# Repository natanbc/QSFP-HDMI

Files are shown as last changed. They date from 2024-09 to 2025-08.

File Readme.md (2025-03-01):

# QSFP to HDMI Breakout Boards

This repository contains two KiCad subprojects for the QSFP to HDMI breakout boards. These subprojects are designed to facilitate the conversion of QSFP signals to HDMI.

The concept has been created to be used on the Microsoft Stratix V FPGA accelerator card "Storey Peak". Jan Marjanovic has created a series of posts about the analysis of the card:

- [Part 1](https://j-marjanovic.io/stratix-v-accelerator-card-from-ebay.html)
- [Part 2](https://j-marjanovic.io/stratix-v-accelerator-card-from-ebay-part-2.html)
- [Part 3](https://j-marjanovic.io/stratix-v-accelerator-card-from-ebay-part-3.html)
- [Part 4](https://j-marjanovic.io/stratix-v-accelerator-card-from-ebay-part-4.html)
- [Part 5](https://j-marjanovic.io/stratix-v-accelerator-card-from-ebay-part-5.html)
- [Part 6](https://j-marjanovic.io/stratix-v-accelerator-card-from-ebay-part-6.html)
- [Part 7](https://j-marjanovic.io/stratix-v-accelerator-card-from-ebay-part-7.html)
- [Part 8](https://j-marjanovic.io/stratix-v-accelerator-card-from-ebay-part-8.html)

## Subprojects

### 1. QSFP breakout board

The project is just a breakout board for the QSFP connector allowing connection to the QSFP on the FPGA board.

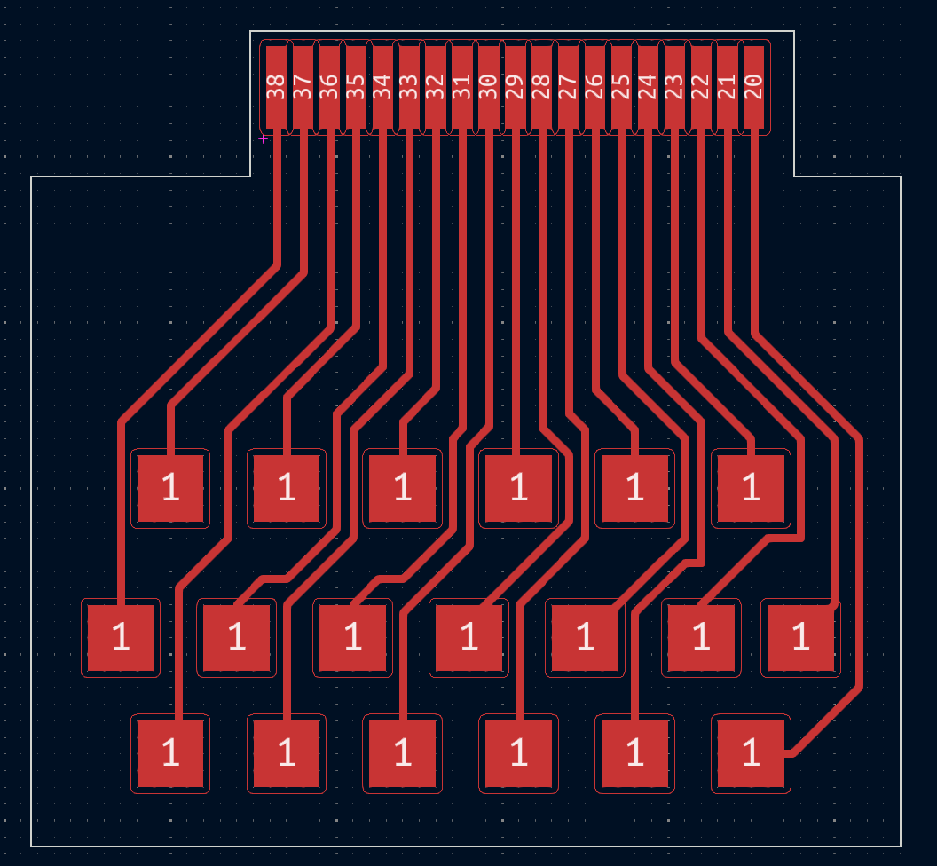
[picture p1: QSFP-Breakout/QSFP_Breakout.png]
PCB


### 2. QSFP to HDMI and UART Adapter

This subproject focuses on the design and implementation of an adapter that converts QSFP signals to HDMI. The key features include:

- QSFP connector for input signals
- HDMI connector for output signals
- USB-C connector for UART adapter

This board has been manufactured in JLCPCB, and has LCSC part numbers allowing assembly by them as well. Be sure to use 1mm PCBs to fit into the QSFP slot.

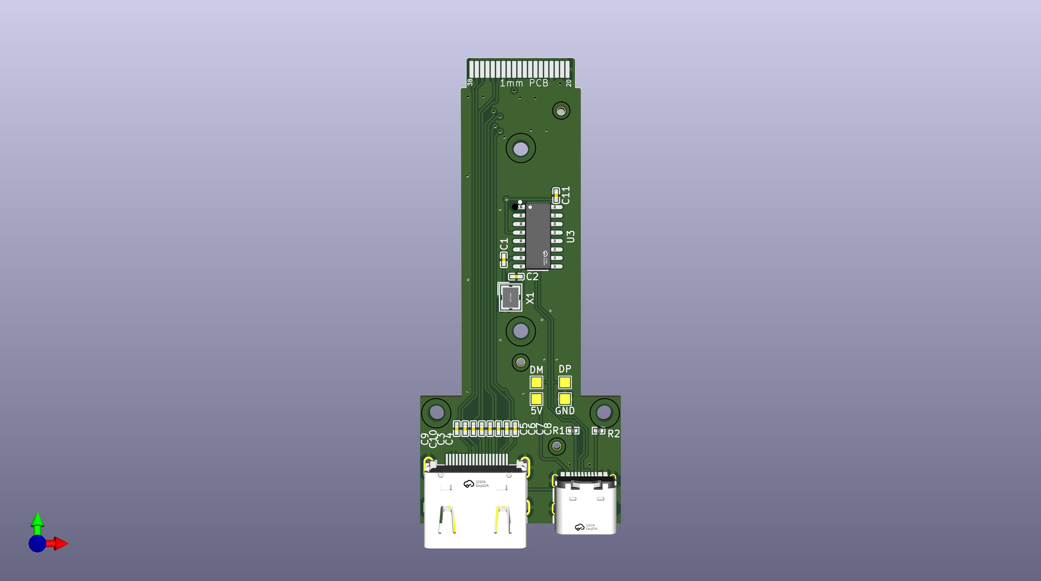
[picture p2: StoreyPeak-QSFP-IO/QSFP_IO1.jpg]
PCB_1


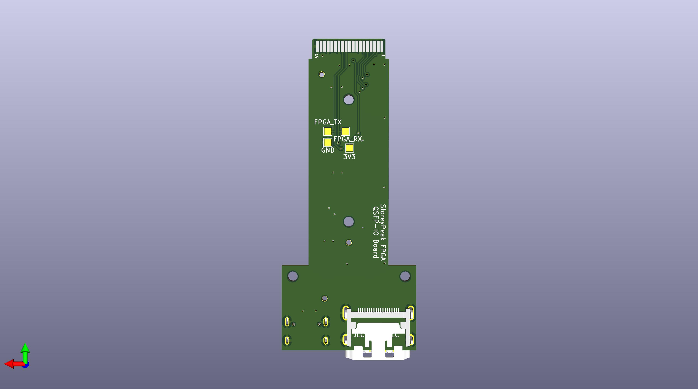
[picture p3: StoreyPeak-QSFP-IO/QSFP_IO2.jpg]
PCB_2


## Contributing

Contributions are welcome! Please fork the repository and submit a pull request with your improvements.

## License

This project is licensed under the MIT License. See the [LICENSE](LICENSE) file for details.

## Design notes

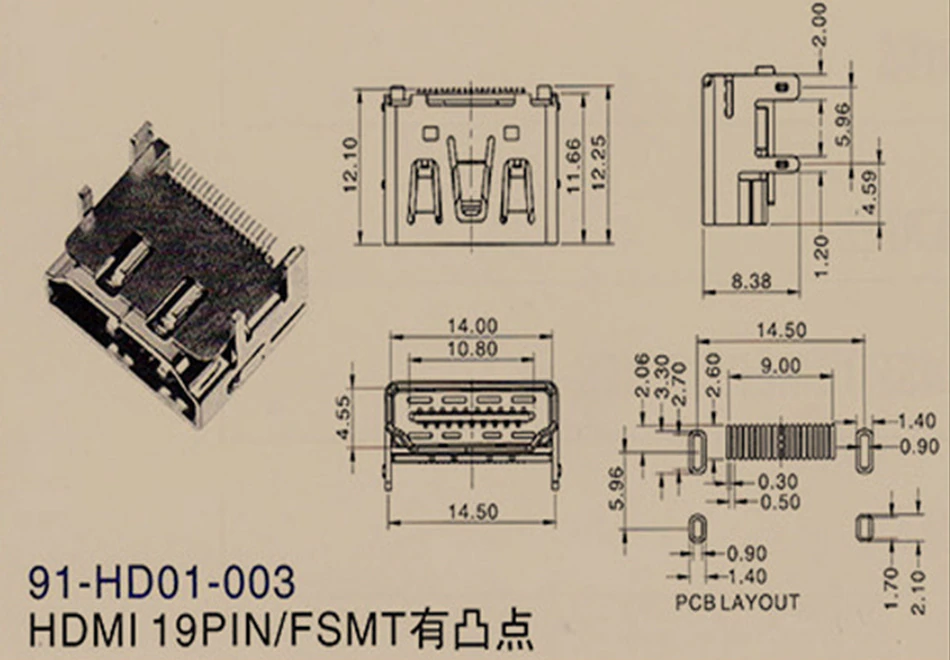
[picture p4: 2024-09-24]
StoreyPeak-QSFP-IO/Reference_imsgs/HDMI-1.webp

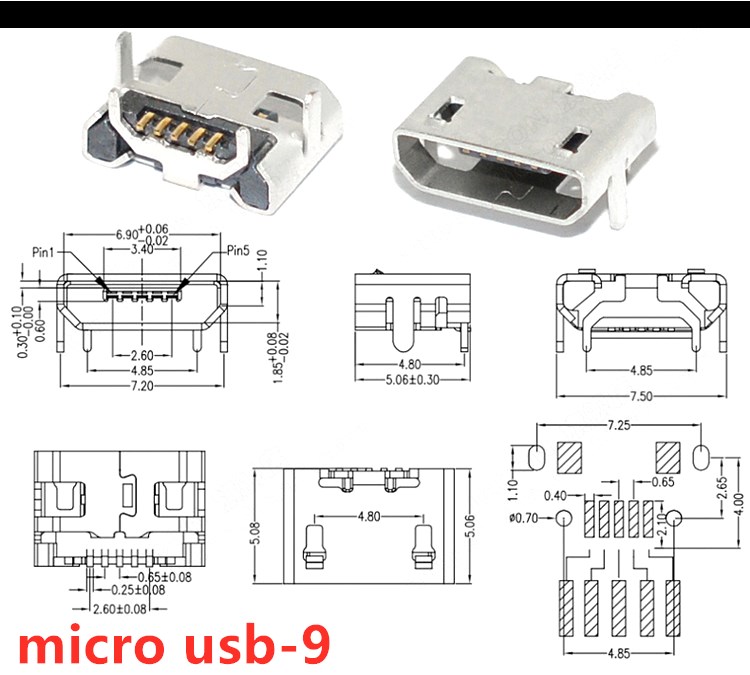
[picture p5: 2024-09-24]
StoreyPeak-QSFP-IO/Reference_imsgs/microUSB-9.jpg

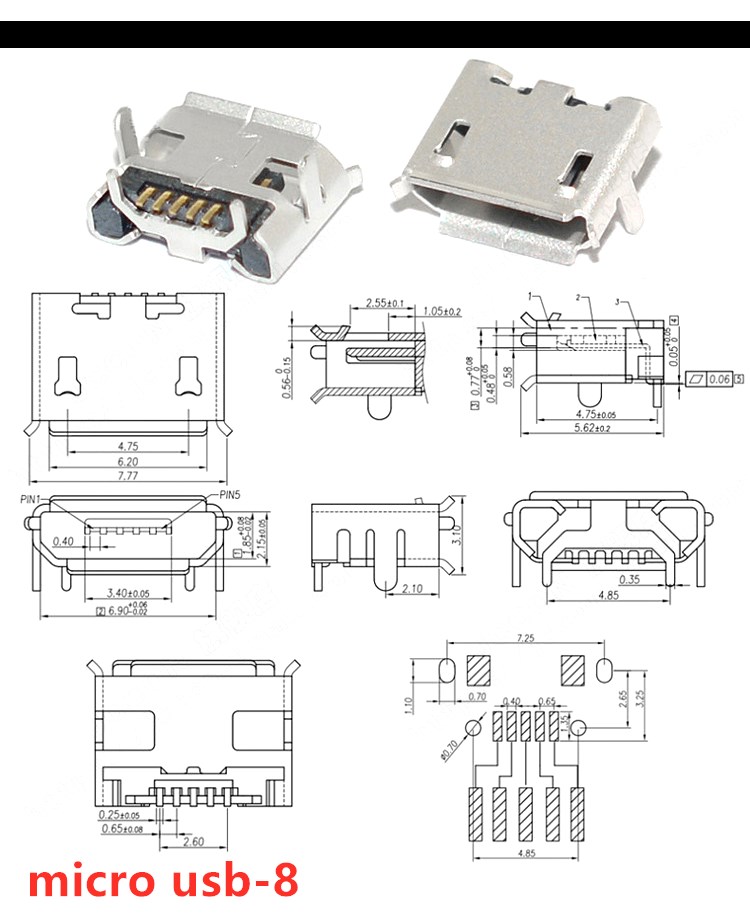
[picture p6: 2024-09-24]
StoreyPeak-QSFP-IO/Reference_imsgs/microUSB-8.jpg

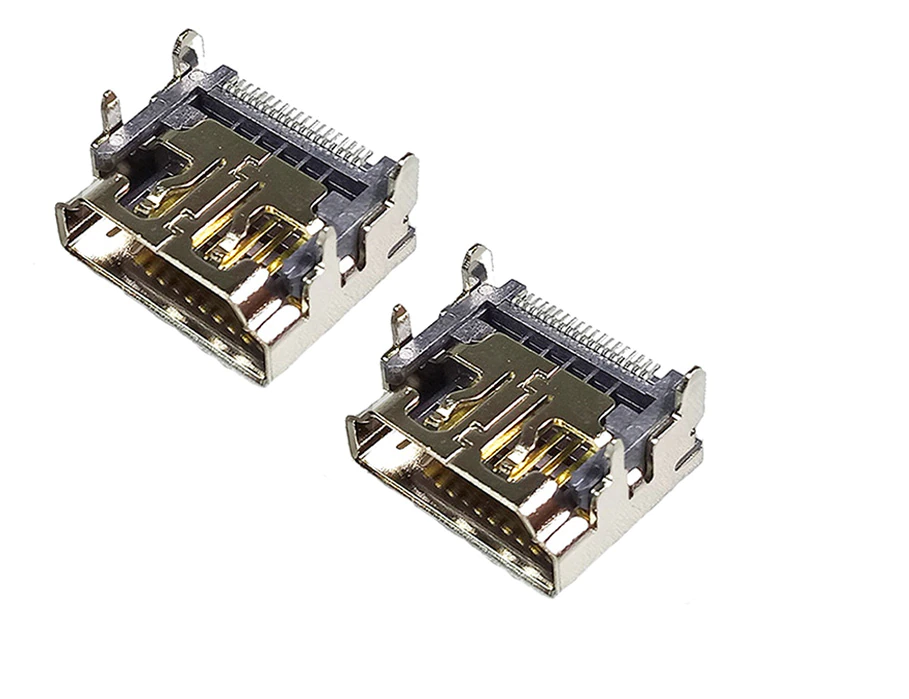
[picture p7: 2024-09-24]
StoreyPeak-QSFP-IO/Reference_imsgs/HDMI-3.webp

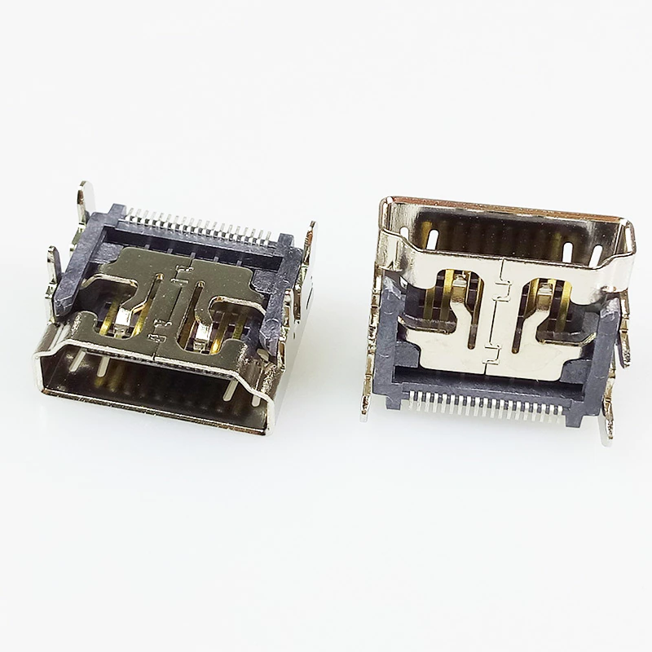
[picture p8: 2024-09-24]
StoreyPeak-QSFP-IO/Reference_imsgs/HDMI-2.webp

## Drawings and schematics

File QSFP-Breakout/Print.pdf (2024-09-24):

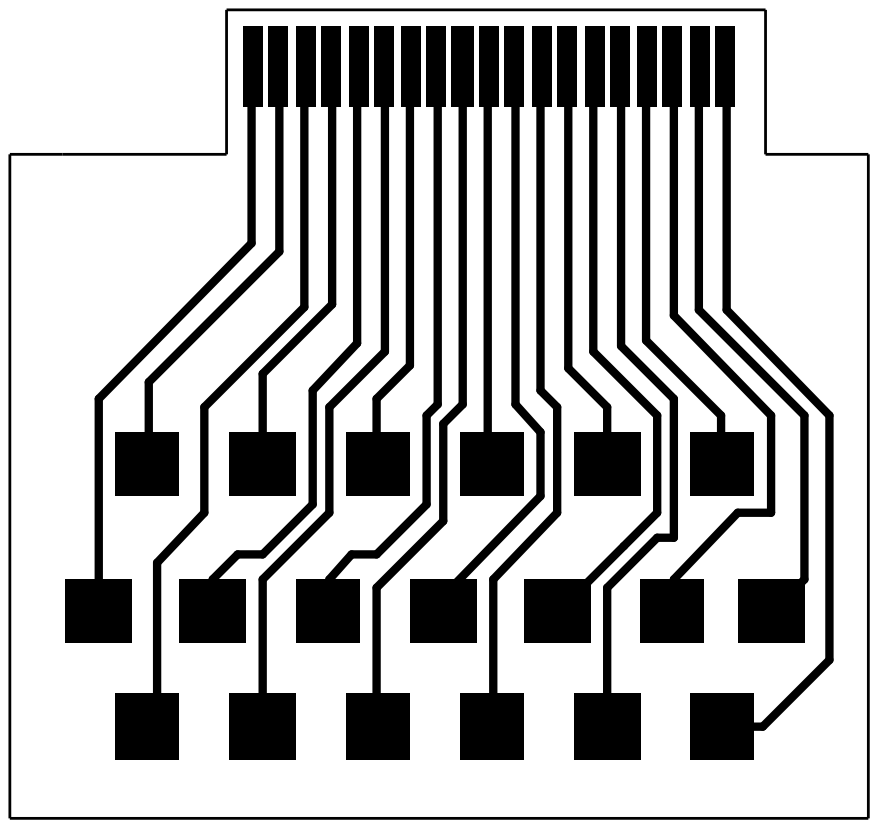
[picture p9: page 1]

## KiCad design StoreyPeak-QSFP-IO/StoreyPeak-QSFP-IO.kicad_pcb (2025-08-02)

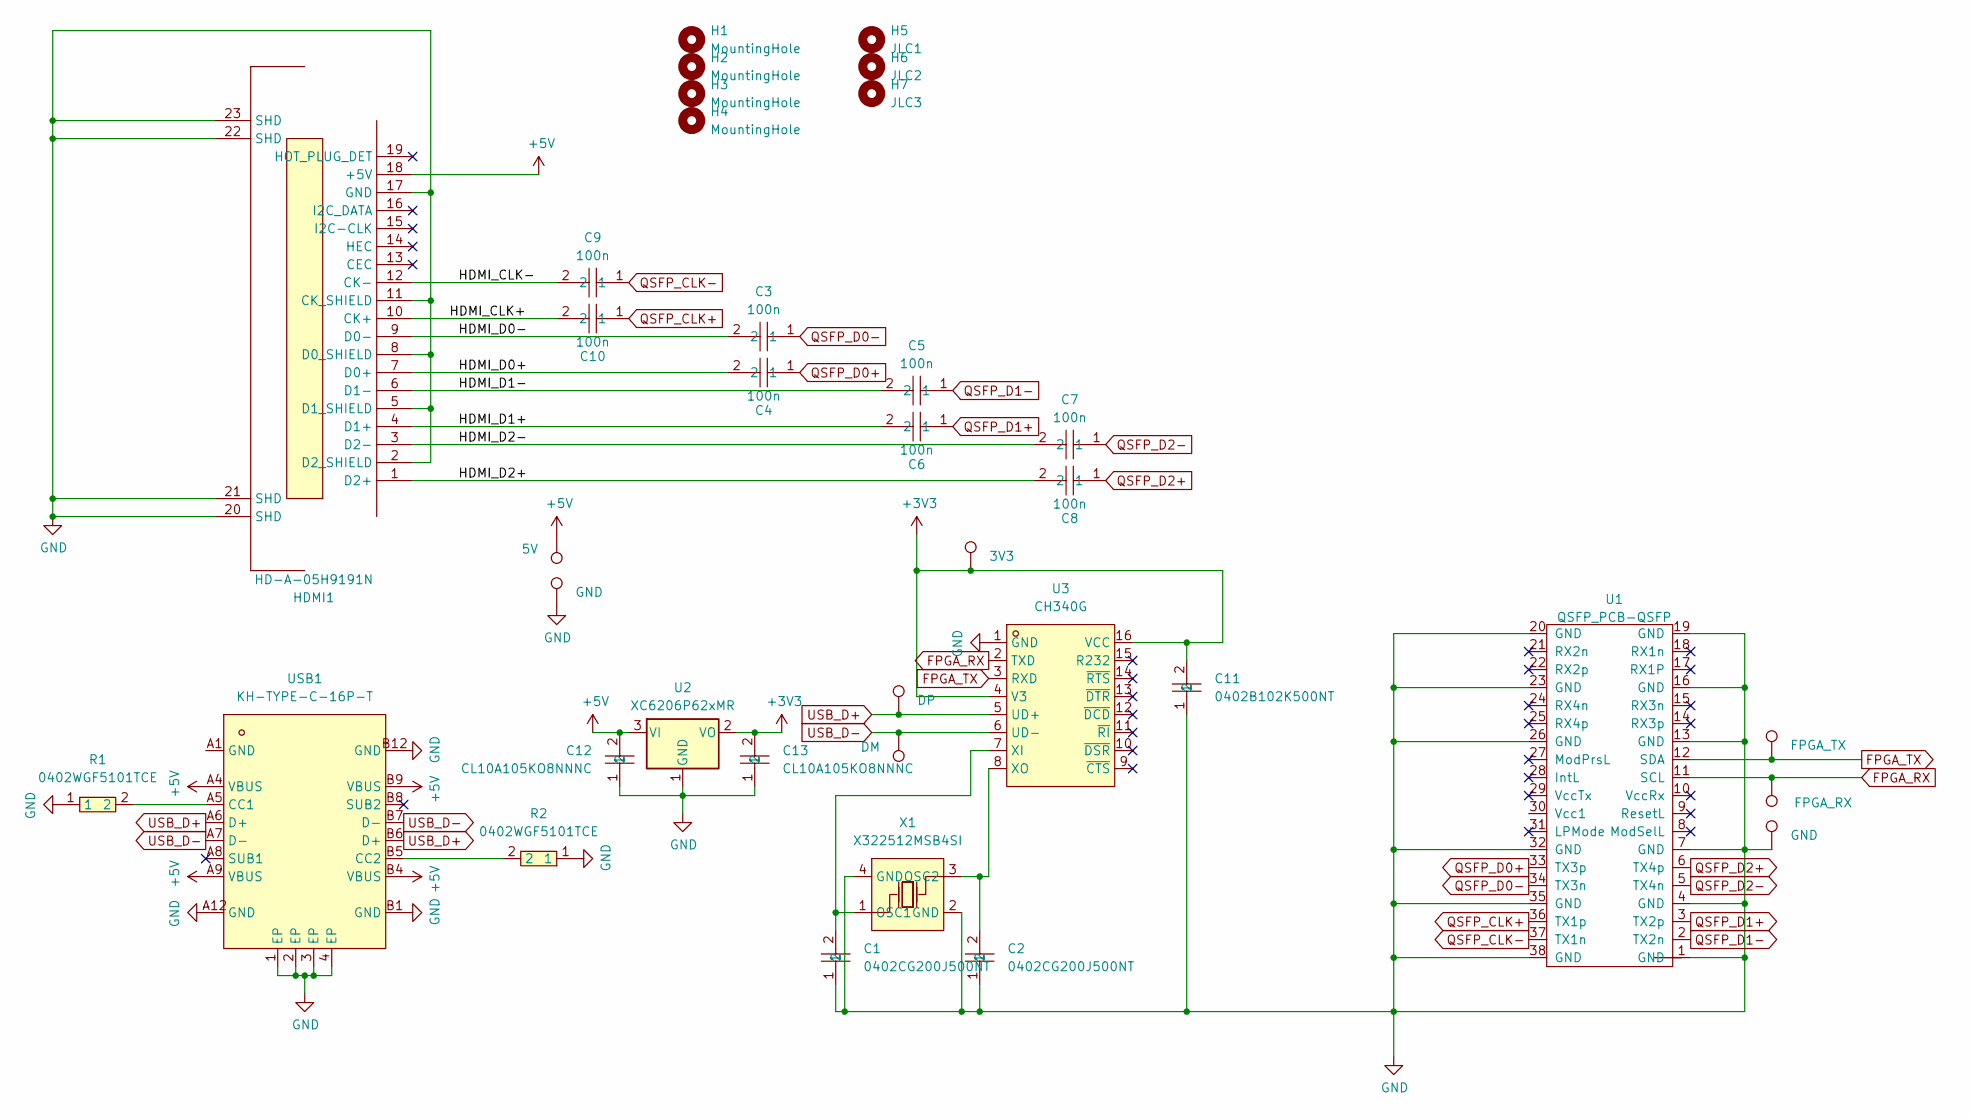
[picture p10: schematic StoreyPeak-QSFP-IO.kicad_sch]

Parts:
C1, C2: 0402CG200J500NT; C0402; LCSC Part C1554
C3, C4, C5, C6, C7, C8, C9, C10: 100n; C0402; LCSC Part C1525
C11: 0402B102K500NT; C0402; LCSC Part C1523
C12, C13: CL10A105KO8NNNC; C_0603_1608Metric; LCSC Part C1592
H1, H2, H3, H4: MountingHole; MountingHole_2.2mm_M2
H5: JLC1; JLCPCB_Tooling_Hole
H6: JLC2; JLCPCB_Tooling_Hole
H7: JLC3; JLCPCB_Tooling_Hole
HDMI1: HD-A-05H9191N; HDMI-SMD_HD-A-05H9192N; LCSC C18213861
R1, R2: 0402WGF5101TCE; R0402; LCSC Part C25905
TP1: 5V; TestPoint_Pad_1.5x1.5mm
TP2, TP7: GND; TestPoint_Pad_1.5x1.5mm
TP3: FPGA_RX; TestPoint_Pad_1.5x1.5mm
TP4: FPGA_TX; TestPoint_Pad_1.5x1.5mm
TP5: DP; TestPoint_Pad_1.5x1.5mm
TP6: DM; TestPoint_Pad_1.5x1.5mm
TP8: 3V3; TestPoint_Pad_1.5x1.5mm
U1: QSFP_PCB-QSFP; QSFP-Edge
U2: XC6206P62xMR; SOT-23-3; LCSC C2891841
U3: CH340G; SOIC-16_L9.9-W3.9-P1.27-LS6.0-BL; LCSC Part C14267
USB1: KH-TYPE-C-16P-T; USB-C-SMD_KH-TYPE-C-16P; LCSC Part C709358
X1: X322512MSB4SI; CRYSTAL-SMD_4P-L3.2-W2.5-BL; LCSC Part C9002

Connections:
+3V3: C11.2, C13.2, TP8.1, U2.2 (VO), U3.4 (V3), U3.16 (VCC); also elsewhere on the board
+5V: C12.2, HDMI1.18 (+5V), TP1.1, U2.3 (VI), USB1.A4 (VBUS), USB1.A9 (VBUS), USB1.B4 (VBUS), USB1.B9 (VBUS)
/HDMI_CLK+: C10.2, HDMI1.10 (CK+)
/HDMI_CLK-: C9.2, HDMI1.12 (CK-)
/HDMI_D0+: C4.2, HDMI1.7 (D0+)
/HDMI_D0-: C3.2, HDMI1.9 (D0-)
/HDMI_D1+: C6.2, HDMI1.4 (D1+)
/HDMI_D1-: C5.2, HDMI1.6 (D1-)
/HDMI_D2+: C8.2, HDMI1.1 (D2+)
/HDMI_D2-: C7.2, HDMI1.3 (D2-)
FPGA_RX: TP3.1, U1.11 (SCL), U3.2 (TXD)
FPGA_TX: TP4.1, U1.12 (SDA), U3.3 (RXD)
GND: C1.1, C2.1, C11.1, C12.1, C13.1, HDMI1.2 (D2_SHIELD), HDMI1.5 (D1_SHIELD), HDMI1.8 (D0_SHIELD), HDMI1.11 (CK_SHIELD), HDMI1.17 (GND), HDMI1.20 (SHD), HDMI1.21 (SHD), HDMI1.22 (SHD), HDMI1.23 (SHD), R1.1, R2.1, TP2.1, TP7.1, U1.1 (GND), U1.4 (GND), U1.7 (GND), U1.13 (GND), U1.16 (GND), U1.19 (GND), U1.20 (GND), U1.23 (GND), U1.26 (GND), U1.32 (GND), U1.35 (GND), U1.38 (GND), U2.1 (GND), U3.1 (GND), USB1.1 (EP), USB1.2 (EP), USB1.3 (EP), USB1.4 (EP), USB1.A12 (GND), USB1.B1 (GND), USB1.B12 (GND), X1.2 (GND), X1.4 (GND)
unnamed: C1.2, U3.7 (XI), X1.1 (OSC1)
unnamed: C2.2, U3.8 (XO), X1.3 (OSC2)
unnamed: R1.2, USB1.A5 (CC1)
unnamed: R2.2, USB1.B5 (CC2)
QSFP_CLK+: C10.1, U1.36 (TX1p)
QSFP_CLK-: C9.1, U1.37 (TX1n)
QSFP_D0+: C4.1, U1.33 (TX3p)
QSFP_D0-: C3.1, U1.34 (TX3n)
QSFP_D1+: C6.1, U1.3 (TX2p)
QSFP_D1-: C5.1, U1.2 (TX2n)
QSFP_D2+: C8.1, U1.6 (TX4p)
QSFP_D2-: C7.1, U1.5 (TX4n)
USB_D+: TP5.1, U3.5 (UD+), USB1.A6 (D+), USB1.B6 (D+)
USB_D-: TP6.1, U3.6 (UD-), USB1.A7 (D-), USB1.B7 (D-)

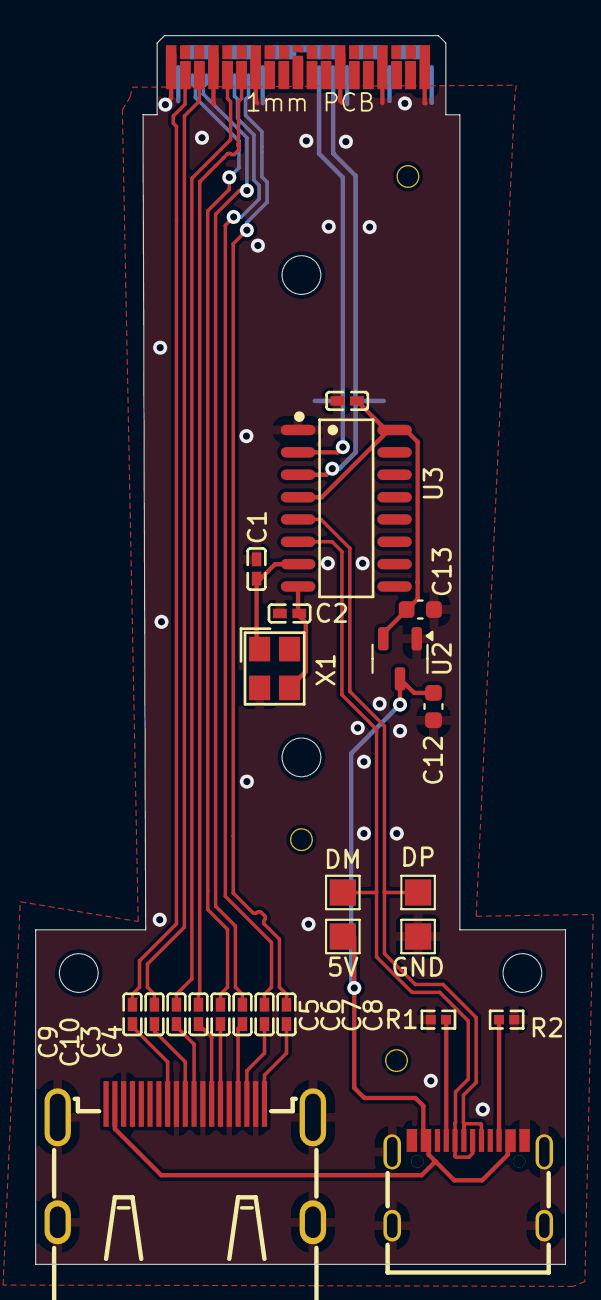
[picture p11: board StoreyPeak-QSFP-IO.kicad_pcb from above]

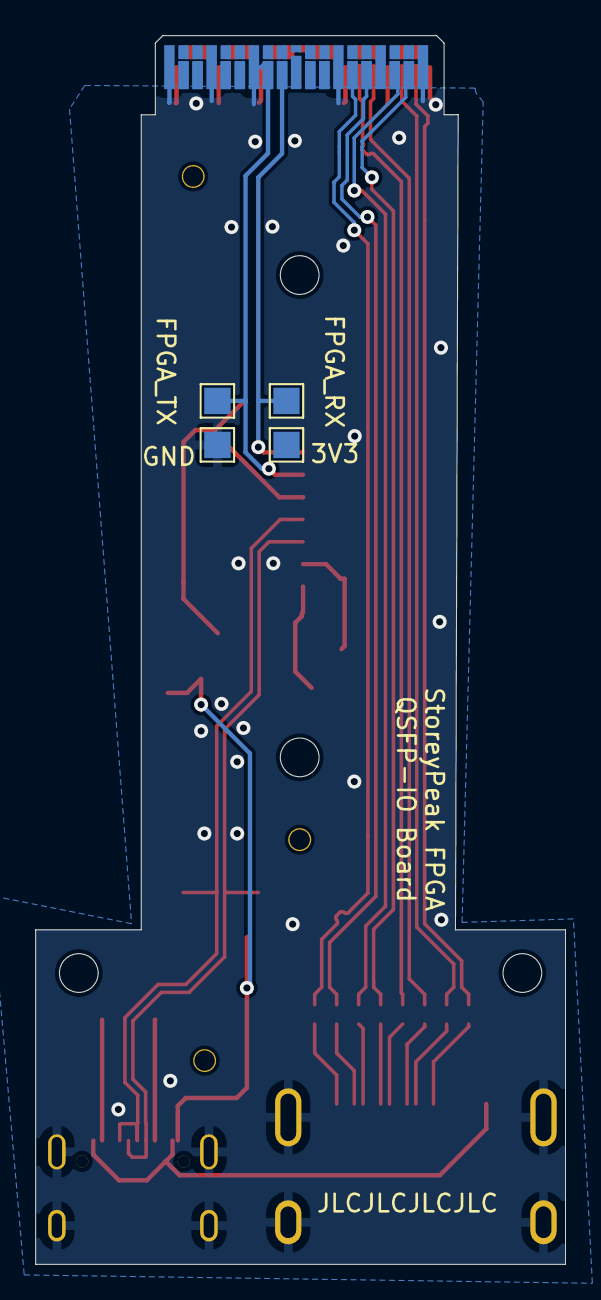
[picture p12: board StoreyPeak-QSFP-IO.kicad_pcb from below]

Board: 2 copper layers, 30.1 x 69.8 mm, 36 parts (4 on the bottom side), 27 nets.

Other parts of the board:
3V3: 3V3; TestPoint_Pad_1.5x1.5mm

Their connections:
+3V3: 3V3.1; also elsewhere on the board

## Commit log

2024-09-24 Initial import
    [QSFP-Breakout.kicad_pcb, QSFP-Breakout.sch, StoreyPeak-QSFP-IO.kicad_pcb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]
2024-12-14 Use CH340G UART and USB-C port
    [StoreyPeak-QSFP-IO.kicad_pcb, StoreyPeak-QSFP-IO.kicad_sch]
2024-12-14 Use passives from JLCPCB basic library
    [StoreyPeak-QSFP-IO.kicad_pcb, StoreyPeak-QSFP-IO.kicad_sch]
2024-12-14 Use SMD crystal instead of THT
    [StoreyPeak-QSFP-IO.kicad_pcb, StoreyPeak-QSFP-IO.kicad_sch]
2024-12-14 Replace more passives with JLCPCB basic parts
    [StoreyPeak-QSFP-IO.kicad_pcb, StoreyPeak-QSFP-IO.kicad_sch]
2024-12-14 Add test points, add screw holes to schematic
    [StoreyPeak-QSFP-IO.kicad_pcb, StoreyPeak-QSFP-IO.kicad_sch]
2024-12-14 Fix board outline cuts
    [StoreyPeak-QSFP-IO.kicad_pcb]
2024-12-15 Re-add vias (oops), add DP/DM pads, extend ground planes to cover entire board, stitch ground planes together
    [StoreyPeak-QSFP-IO.kicad_pcb, StoreyPeak-QSFP-IO.kicad_sch]
2024-12-15 Change board to 1mm
    [StoreyPeak-QSFP-IO.kicad_pcb]
2025-01-25 Change QSFP->HDMI mapping for better routing, skew match diffpairs
    [StoreyPeak-QSFP-IO.kicad_pcb, StoreyPeak-QSFP-IO.kicad_sch]
2025-01-25 Add GND pad next to UART pads, reroute 5V pad to avoid breaking GND plane below HDMI signals
    [StoreyPeak-QSFP-IO.kicad_pcb, StoreyPeak-QSFP-IO.kicad_sch]
2025-01-25 Re-add accidentally deleted UART GND pad, move some traces to avoid cutting ground planes
    [StoreyPeak-QSFP-IO.kicad_pcb]
2025-02-02 Add JLCPCB tooling holes
    [StoreyPeak-QSFP-IO.kicad_pcb, StoreyPeak-QSFP-IO.kicad_sch]
2025-03-01 Fix QSFP connector footprint (pins 1-19 were flipped)
    [StoreyPeak-QSFP-IO.kicad_pcb]
2025-03-01 Fix board for right QSFP connector, change HDMI caps to 0402
    [StoreyPeak-QSFP-IO.kicad_pcb, StoreyPeak-QSFP-IO.kicad_sch]
2025-03-01 Increase clearance on USB pads for the casing
    [StoreyPeak-QSFP-IO.kicad_pcb]
2025-03-16 Connect all USB-C GND pins to ground plane
    [StoreyPeak-QSFP-IO.kicad_pcb]
2025-06-04 Hide part numbers that started showing after updating to KiCad 9
    [StoreyPeak-QSFP-IO.kicad_pcb]
2025-06-09 Get 3.3V from LDO off USB port
    [StoreyPeak-QSFP-IO.kicad_pcb, StoreyPeak-QSFP-IO.kicad_sch]
2025-07-12 Connect HDMI ground pins
    [StoreyPeak-QSFP-IO.kicad_pcb, StoreyPeak-QSFP-IO.kicad_sch]
2025-07-12 Remove 3V3 text on back
    [StoreyPeak-QSFP-IO.kicad_pcb]
2025-08-02 Fix wrong footprint for QSFP edge connector
    [StoreyPeak-QSFP-IO.kicad_pcb, StoreyPeak-QSFP-IO.kicad_sch]
2025-08-02 Readd 3V3 test point
    [StoreyPeak-QSFP-IO.kicad_pcb, StoreyPeak-QSFP-IO.kicad_sch]
2025-08-02 Fix flipped text on bottom silkscreen
    [StoreyPeak-QSFP-IO.kicad_pcb]
